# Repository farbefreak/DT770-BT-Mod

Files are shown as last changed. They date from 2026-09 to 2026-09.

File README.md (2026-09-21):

This modification adds Bluetooth, USB-C charging and Audio support to DT-770 Pro Headsets from beyerdynamic.
======

A DIY hardware modification for Beyerdynamic headphones.

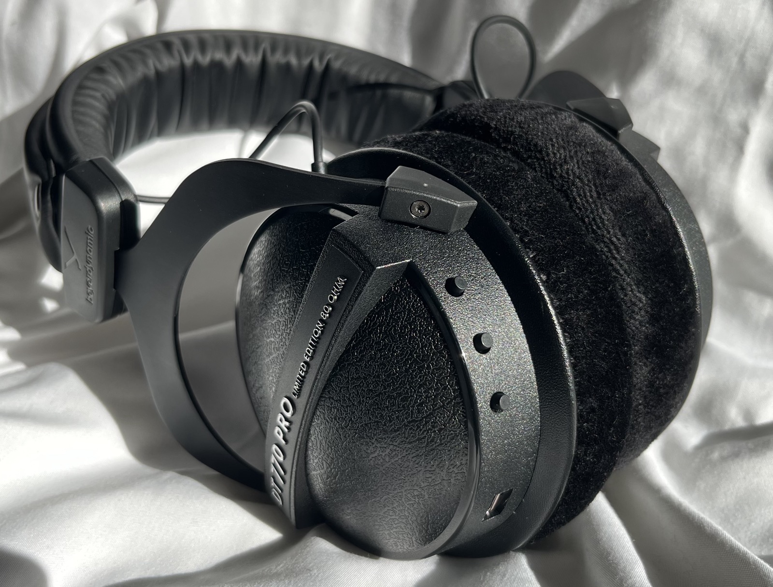
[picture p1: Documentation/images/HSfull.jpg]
Headset full


This project provides everything needed to build the modification yourself, including the PCB design, firmware, 3D-printable parts and a complete assembly guide.
The project is designed to be relatively easy to build. No specialized equipment is required, but basic soldering and mechanical skills are necessary.

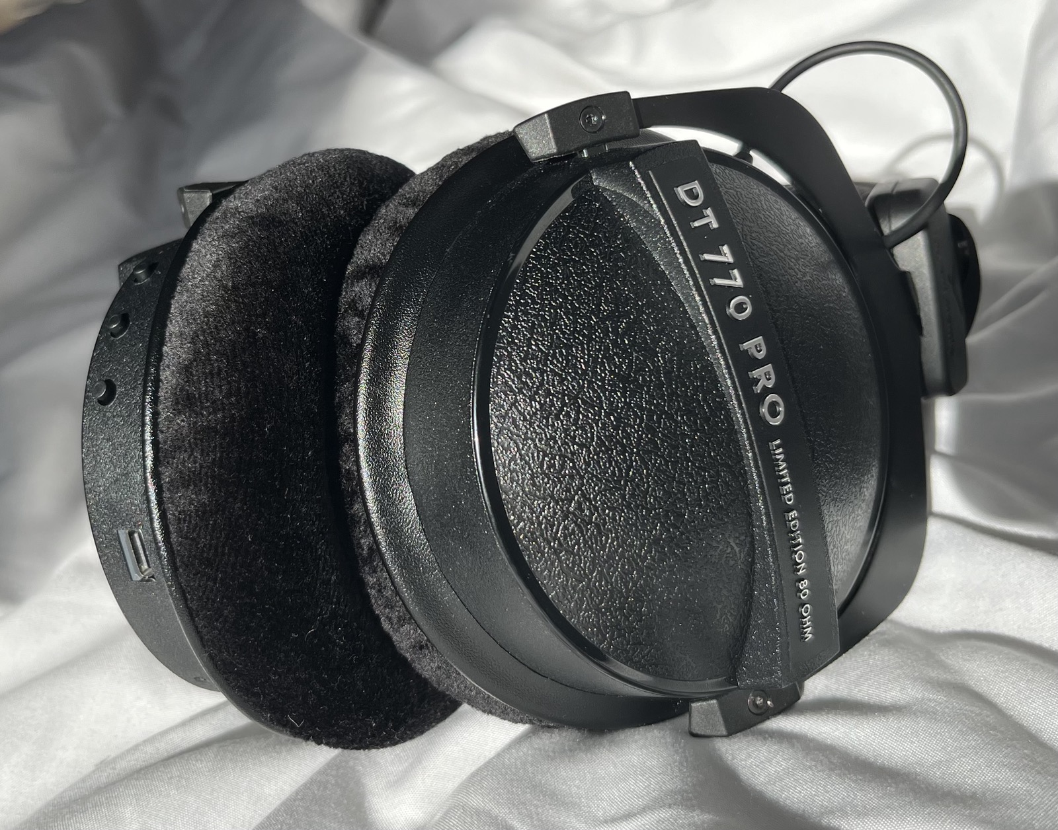
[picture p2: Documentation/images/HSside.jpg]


The modification adds full Bluetooth aptX and A2DP support by using the QCC3008 Chipset. It converts the DT 770 to a fully functional Bluetoooth headset including a microphone back channel and AVRCP controls. (Play/Pause/Vol+/Vol-/Fwrd/Back)
It also adds USB-C battery charging and USB Audio transport. So the Headphones can still be used wired with a USB-C cable.

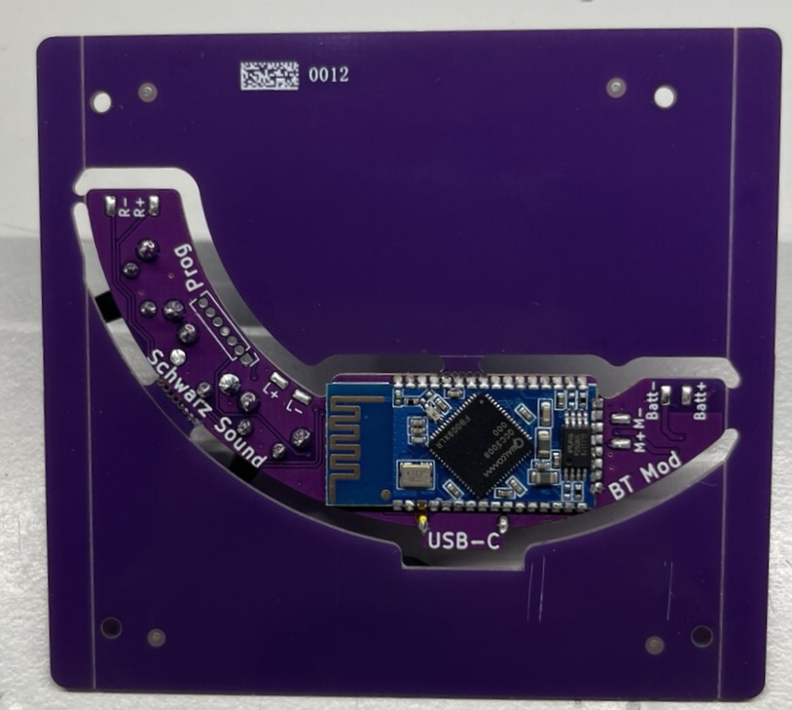
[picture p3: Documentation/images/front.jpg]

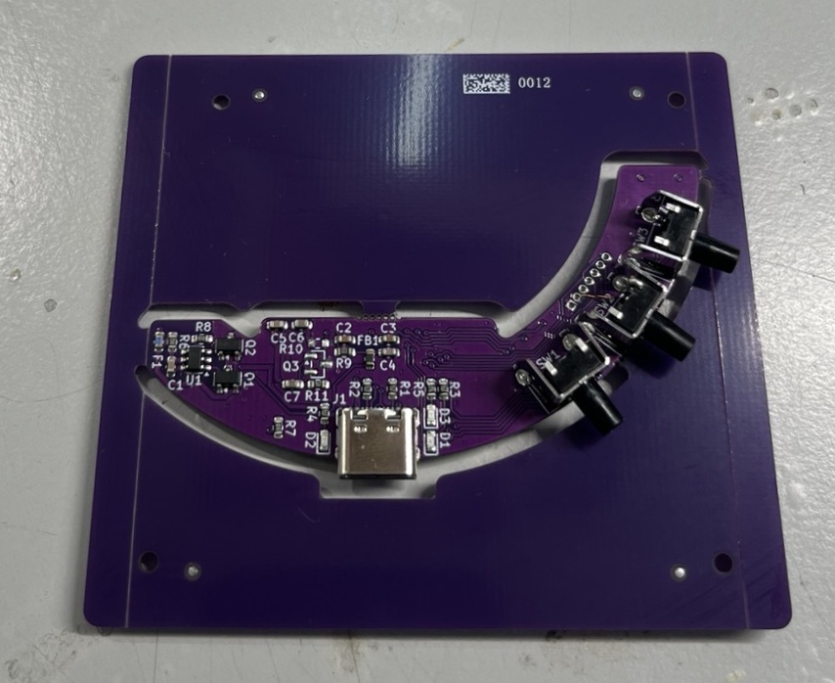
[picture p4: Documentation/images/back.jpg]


The assembly guide can be found in the documentation folder.

### Disclaimer

This project is an independent modification for Beyerdynamic headphones and is not affiliated with, endorsed by, or sponsored by Beyerdynamic
This project involves modification of electronic equipment. The author provides the hardware designs, firmware and documentation "AS IS", without warranty of any kind.
The author assumes no responsibility for damage to headphones, batteries, electronic components, personal property or persons resulting from the use, modification, manufacture or installation of this project.
Use and modification of the project is entirely at the your own risk.

### License

This project is available for personal and non-commercial use.
You are free to study, build and modify the project for your own personal use.
Commercial manufacture, sale or distribution of the project or derivatives is not permitted without explicit permission from the author.

Have fun building!

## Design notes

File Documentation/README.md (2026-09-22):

Assembly
======

# Materials & tools

Tools you need:
* Soldering Iron + Solder + Flux
* Wire Stripper
* T2 Screwdriver
* Flathead Screwdriver
* 4,2mm and 2mm Drill + means of holding it, a battery powered drill works but a Pin Vice would be more controlled
* Hotglue gun
* FDM 3D printer
* SLA 3D printer
* CSR USB SPI Programmer - search for CSR USB-SPI programmer on aliexpress or use this project: https://github.com/lorf/csr-spi-ftdi

Parts:
* Assembled PCB including QCC3008 - QCC3008 on module can be brought on aliexpress, search for BTM306 
* Lithium battery (see below what to choose)
* 6mm Microphone capsule
* DT 770 headphones
* 26AWG / 0,15mm^2 Wire

# Process steps:
+ Print all the parts
+ Program the PCB
+ disassemble the Headphones
+ attach the Lightpipe
+ solder the microphone and glue it into the Headphone casing
+ glue the PCB in
+ solder the battery
+ assemble everything

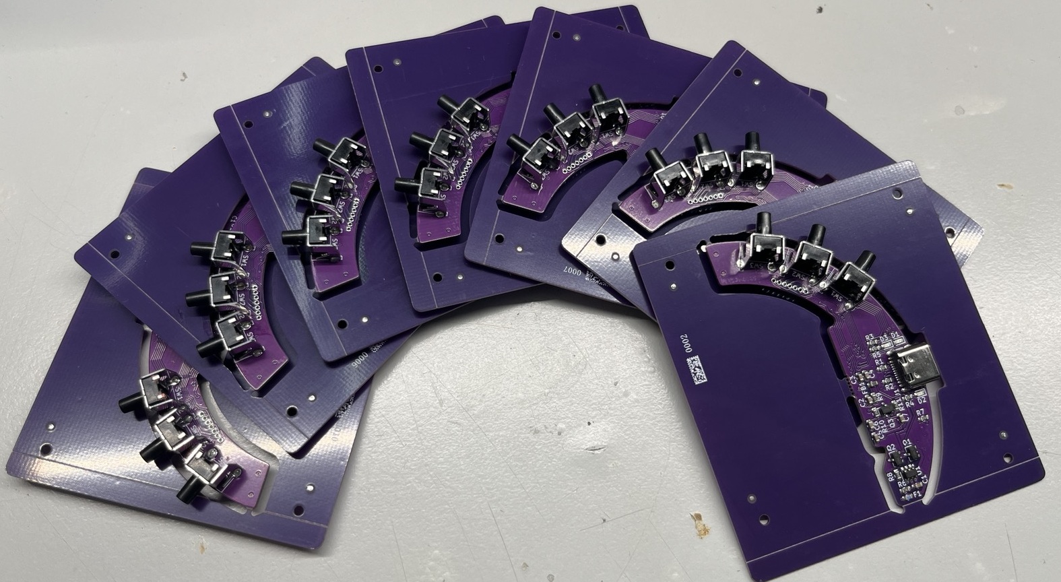
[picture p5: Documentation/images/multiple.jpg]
PCBs


# Programming
Solder a 1,27mm Pin header to some wires. To program the PCB just plug the pin header into the PCB and hold it on an angle to make contact. 
Pin out is self explanatory, check the PCB files and labelling on the programmer.
"+BATT" doesn't need to be connected if you already have a battery connected. Without a battery, this pin can be connected to the 3,3V output of the CSR USB to supply power to be PCB while programming.
Upload the Config file with the "ADK Configuration Tool". 
+ Open the program
+ connect programmer to PCB
+ select the right device
+ click "go configurable"
+ hold play/pause button to enable PCB
+ under File click "Open Config Set Dump"
+ click "Write Device"
+ click "Go Normal"
done

Set the Bluetooth name by opening PSTool.
Select the right device click "ok" and use the filter to search for "Name".  Add your desired name and click "Set" followed by "Reset & Close" -> done.

# Battery

Many different battery will work. You trade off battery runtime with internal volume and added weight. 
I used a 7,6mm x 18mm x 55mm cell with 600mAh. This cell is relatively big and needs modifications to the internal "cage". Three posts need to be cut out.
The maximum size that fits in the internal cage without modification is 8x10x50mm. so a 801050 cell. This cell fits in the internal slot of the cup.
Even a 100mAh cell will give good batter runtime of ~ 5h depending on listening volume.
A protected cell isn't necessary here as the circuit already includes short circuit, over charge and over discharge protection. 
The current PCB doesn't feature a battery NTC to halt charging at extreme temperatures. So make sure to only charge in room temp environments. (or change the PCB and software to include it)

# LED Indicators
There are 3 LEDs to display the current status Red/Green/Blue. The light pipe makes them visible on the USB-C port.
Everything here can be configured according to your liking. The current config file results in the following behaviour:
* Red LED -> shows battery status and charging status. When the battery state is lower than 10%, the red lights starts pulsing. When charging, the red light is solid.
* Blue LED -> shows Bluetooth availability, when no bluetooth device is connected this light is flashing
* Green LED -> shows connection and charging status, when a Bluetooth device is connected this LED fades slowly. When a device is sending audio, this light fades fast. When the battery is fully charged, this light turns solid.

# Button functions
The three buttons can be reconfigured. Current setup reacts like this:
* Upper button -> "single click" Volume increase, "click and hold" Volume increase constantly, "Double click" next title
* Upper button -> "single click" play/pause, "click and hold" power off/on, "Double click" enter bluetooth peering
* Lower button -> "single click" Volume decrease, "click and hold" Volume decrease constantly, "Double click" last title

## Disassembly
###### Attention! The pictures show revision 1 of all the parts. The microphone placement and pcb changed a little. The guide still works the same.

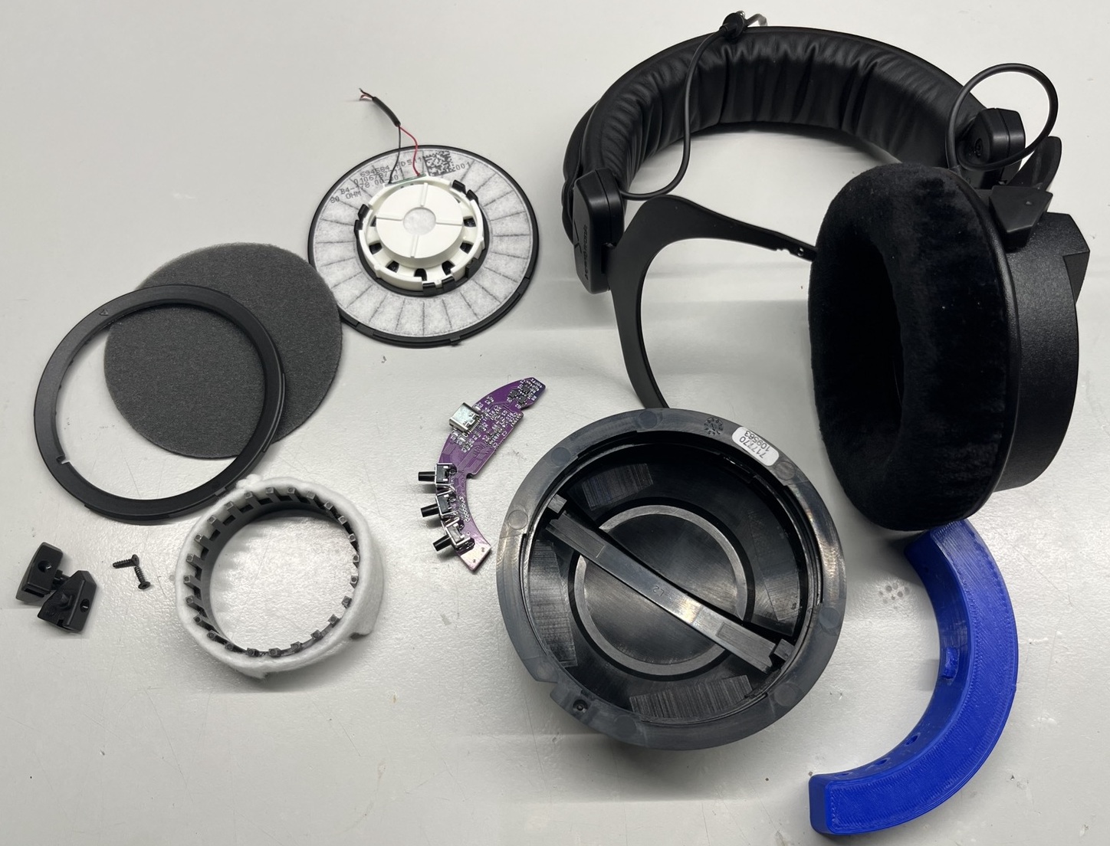
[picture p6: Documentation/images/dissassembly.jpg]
Disassembly


Use the T2 screwdriver to remove the headband holders from the left ear cup. Remove the ear cushions by carefully sliding them from the rim.
A flathead screwdriver can now be inserted in slots around the ring that hold the driver inside. Use a prying motion to unclip the ring. 
Desolder all wires from the driver - including the wire for the right side driver as well as the audio input cable. 
Remove both cables from the cup by pulling the metal clips from the strain relive. 
The left Earcup should now be completely free.
Keep all the parts safe except for the Audio input wire. It can be discarded as its not needed anymore.

## Cup modifications

Attach the printed drill guide by sliding it into the bottom hole (the one where the audio cable used to be).

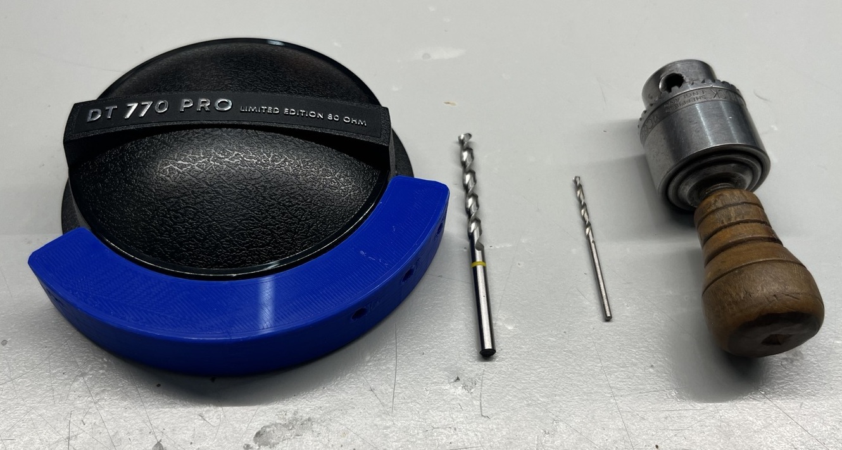
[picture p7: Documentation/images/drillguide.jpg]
drillguide


Drill the 2mm microphone hole first. Its location isnt super critical. Keep the 2mm drill bit in the formed hole to keep the guide aligned while drilling the button holes.

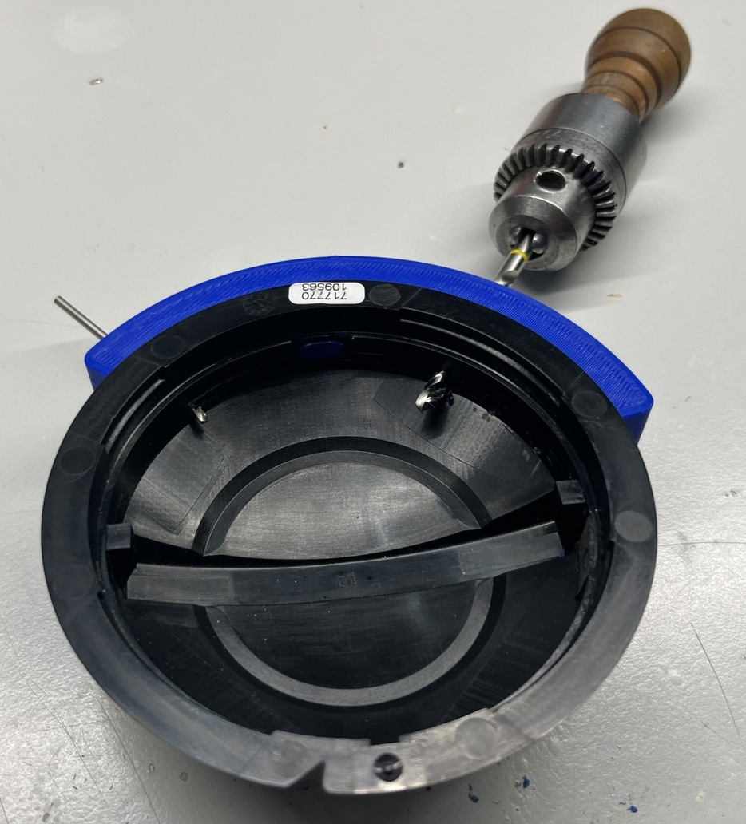
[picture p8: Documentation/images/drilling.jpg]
drilling


Drill the remaining 3 holes. Make sure to keep the guide aligned. Its easy with a pin vice but a battery powered drill works too.

You should end up with 4 clean holes afterwards. 

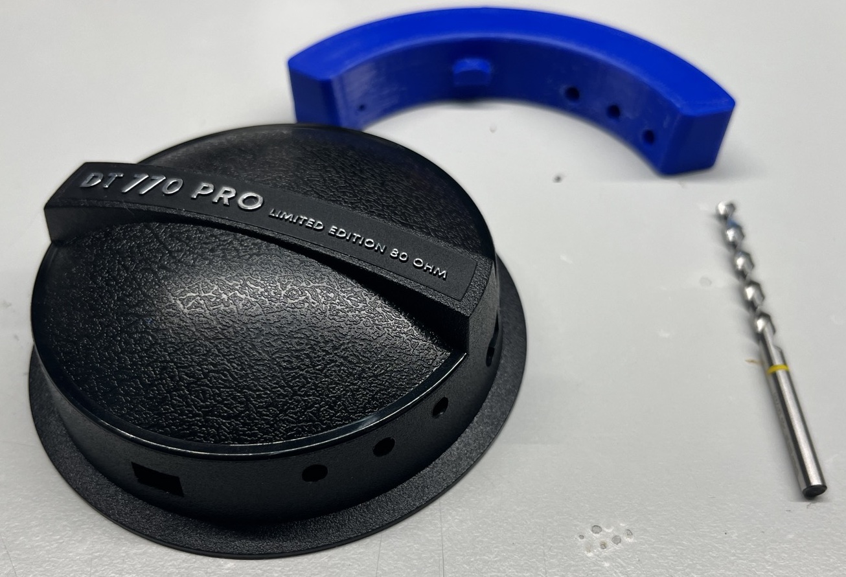
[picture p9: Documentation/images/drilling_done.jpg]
Drilling Done


## Microphone

Glue the printed Mic holder into the ear cup centered over the drilled 2mm hole. Use the angled face on the print to align the holder. Make sure to not fill the 2mm hole or the printed part. Just a little glue on the outside is all thats needed. 

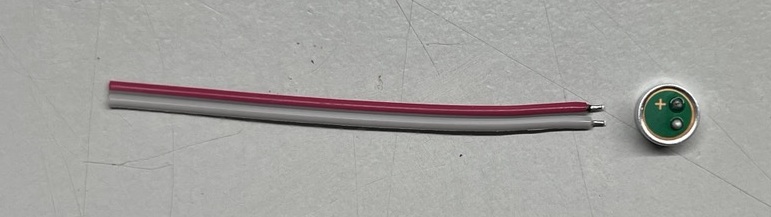
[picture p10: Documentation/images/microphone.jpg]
microphone


Solder 50mm wire to the Mic. I used color coded flat ribbon but everything works. You can even use a bit of the discarded audio input wire. 

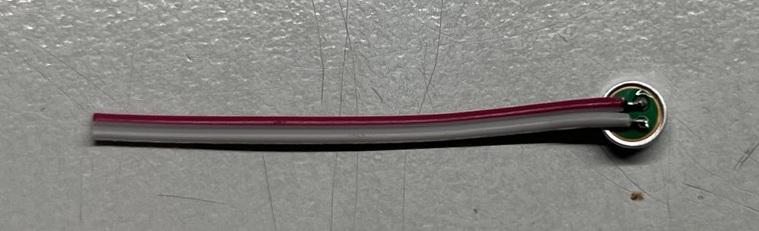
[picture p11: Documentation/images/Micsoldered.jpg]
microphone soldered


Press the mic into the printed holder and seal the backside with hotglue.

## Lightpipe

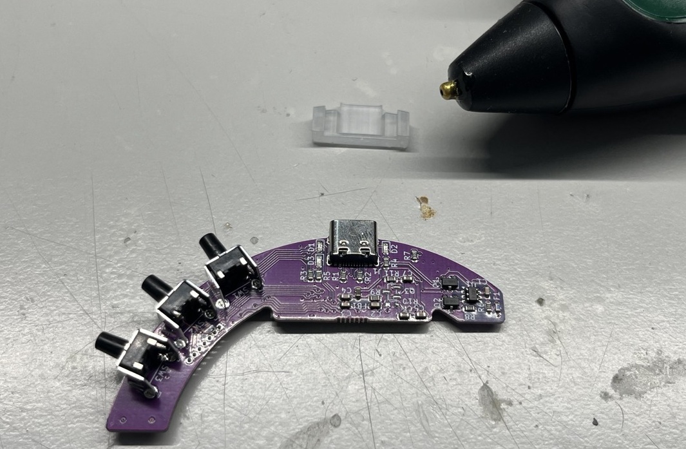
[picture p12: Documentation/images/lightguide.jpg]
lightguide


###### Use translucent Hotglue!
Apply two small drops of hot glue to the LEDs next to the USB-C connector. Press the lightpipe into it and keep it aliged to the PCB edge while the glue is still warm.

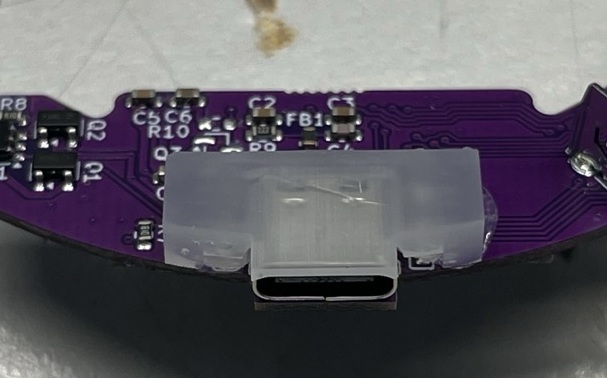
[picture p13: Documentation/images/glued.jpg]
glued


Sqeeze out left and right of the connector doesnt matter and is expected. It wont interfere so dont worry about it.

## Glue the PCB into the earcups

Slide the PCB into the housing. Start with the upper button and work your way towards the USB connector. 

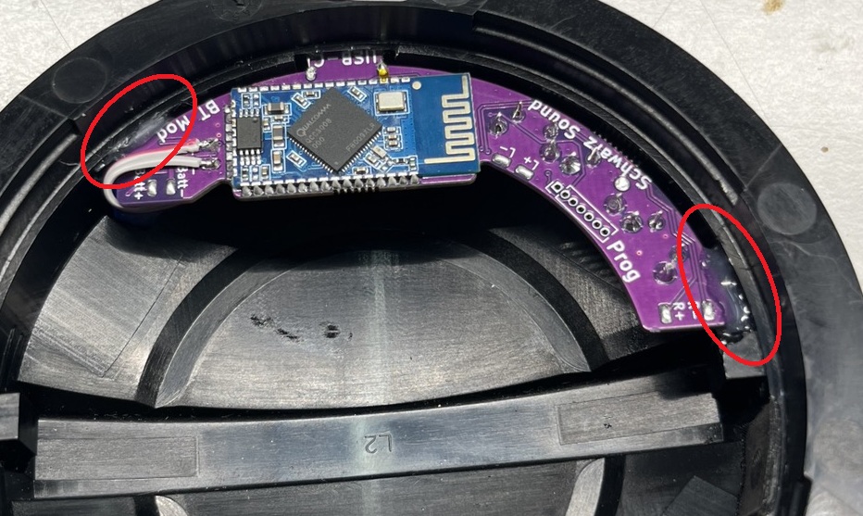
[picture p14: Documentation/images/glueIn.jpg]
PCB glued


Apply two small drops of hot glue to keep it in place. Make sure the board is aligned while the glue hardens. 
Repeatedly click the buttons to make sure they spring back. If the board isn't aligned properly, the button may stay stuck!

## Solder the wires 

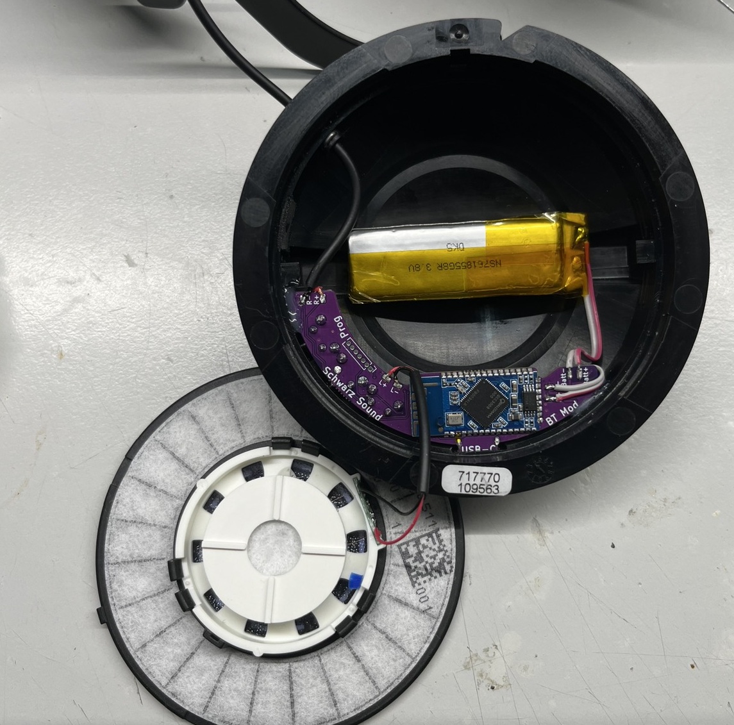
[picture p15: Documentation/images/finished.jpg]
Done


Attach the battery last. The board goes live when you do so solder the drivers and microphone first to avoid shorts.

Now you are almost done. Close the headphones up - same as disassembly but in reverse ;)
Check for interference by checking if the driver sits flush and doesnt apply force to anything. Make sure all wires are where they belong and clip the ring back in. 

I found it easiest to twist the ear cushions onto the rim.

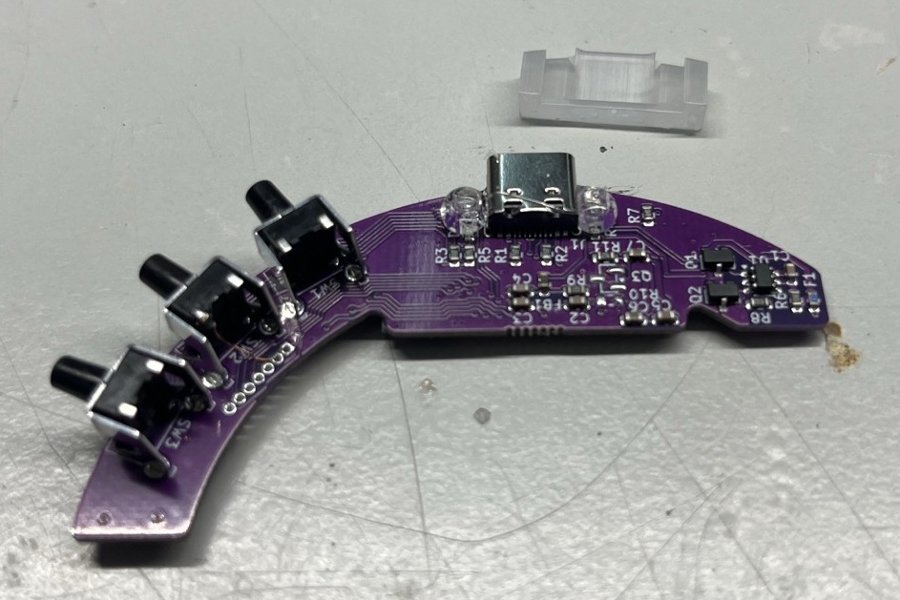
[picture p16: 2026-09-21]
Documentation/images/Lightpipe_glue.jpg

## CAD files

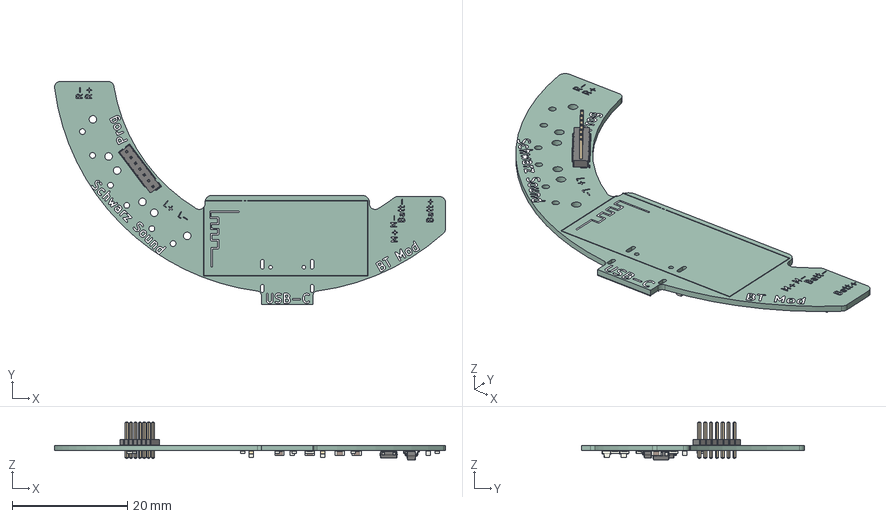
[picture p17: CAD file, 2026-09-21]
Mechanical/PCB.step
67.9 x 38.8 x 6.59 mm
PinHeader_1x07_P127mm_Vertical
C_0603_1608Metric x 6
LED_0603_1608Metric x 3
SOT-23-6
R_0603_1608Metric x 10
L_0603_1608Metric
SOT-23 x 2
Fuse_0603_1608Metric
DT770 Bluetooth Mod_silkscreen x 2
DT770 Bluetooth Mod_PCB

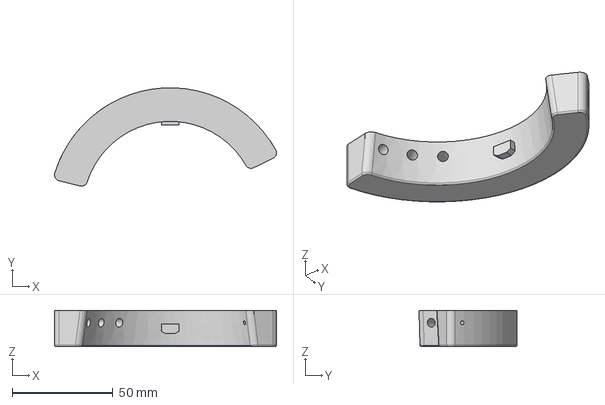
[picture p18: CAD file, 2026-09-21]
Mechanical/drillguide.step
110.3 x 48.9 x 18.0 mm

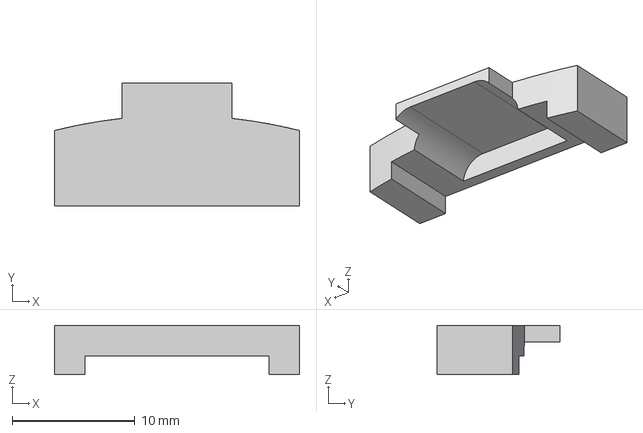
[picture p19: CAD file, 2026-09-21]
Mechanical/Lightguide.step
20.0 x 10.0 x 4.00 mm

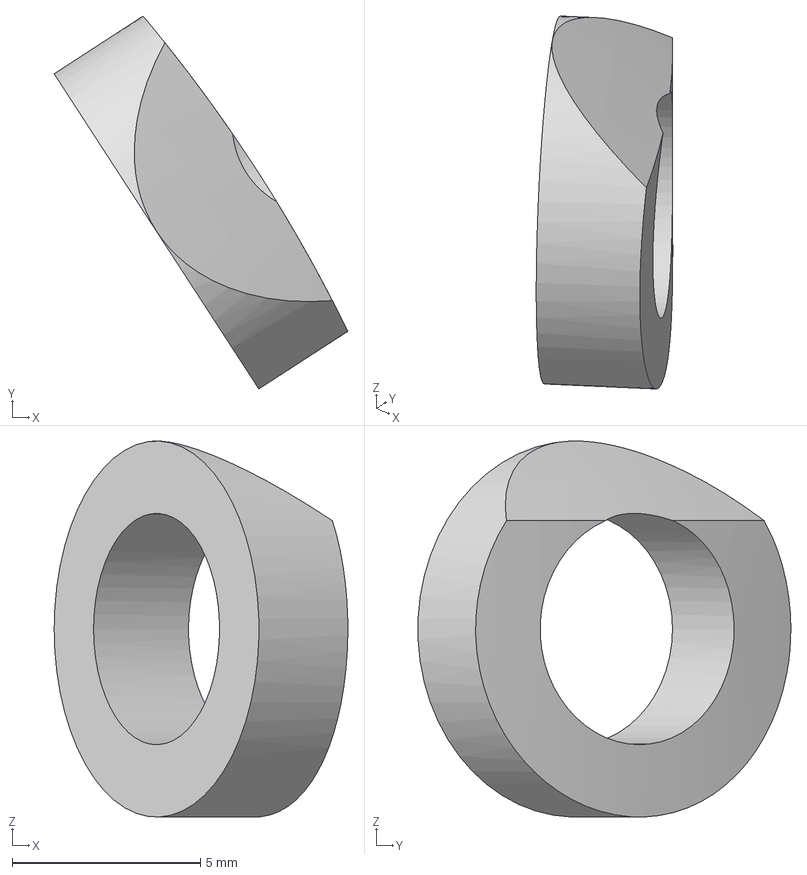
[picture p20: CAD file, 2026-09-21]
Mechanical/microphone_holder.step
7.81 x 9.92 x 10.00 mm

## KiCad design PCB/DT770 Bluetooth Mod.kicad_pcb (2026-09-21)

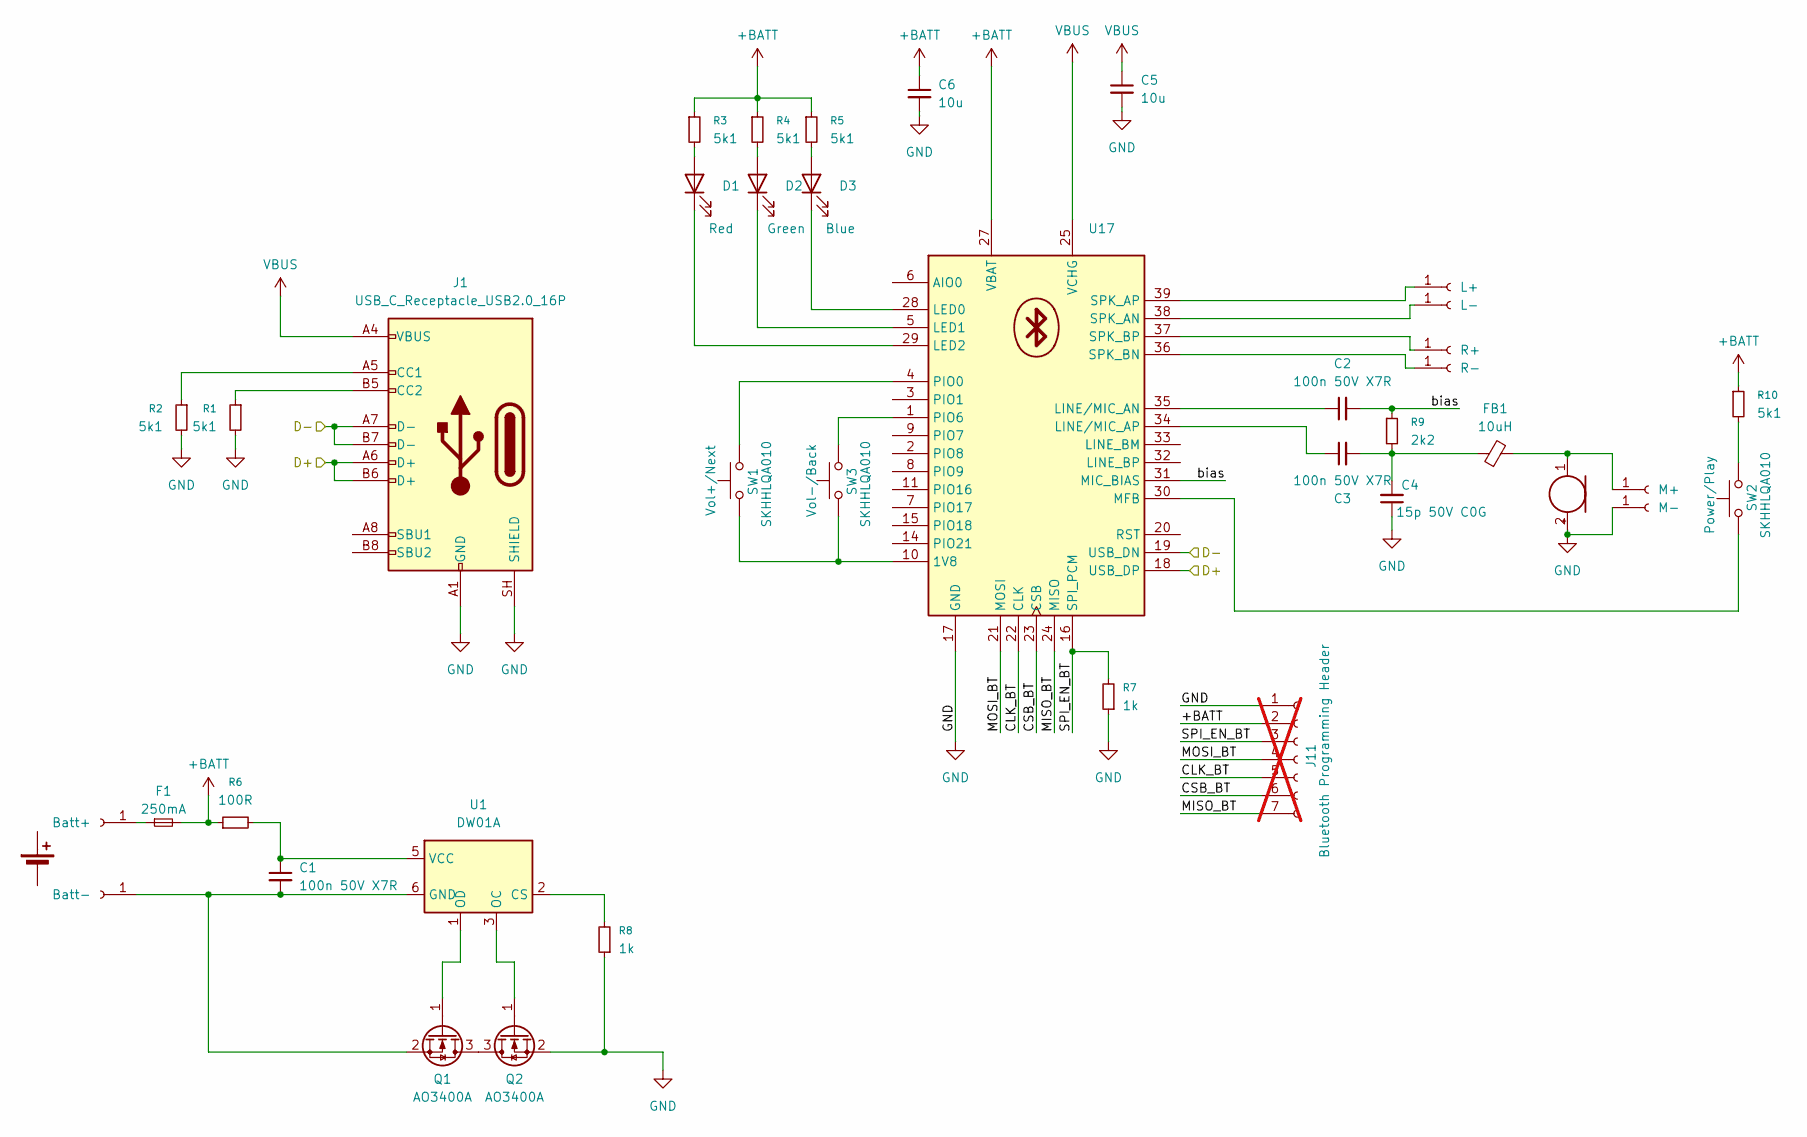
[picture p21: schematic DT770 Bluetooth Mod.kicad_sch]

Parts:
BT1: Battery_Cell
C1, C2, C3: 100n 50V X7R; C_0603_1608Metric; MPN CC0603KRX7R9BB104; LCSC C14663
C4: 15p 50V C0G; C_0603_1608Metric; MPN CL10C150JB8NNNC; LCSC C1644
C5, C6: 10u; C_0603_1608Metric; Voltage 10V; MPN CL10A106KP8NNNC; LCSC C19702
D1: Red; LED_0603_1608Metric; MPN CT-1608URC-P4; LCSC C52675987
D2: Green; LED_0603_1608Metric; MPN CT-1608UGC-P4; LCSC C52675989
D3: Blue; LED_0603_1608Metric; MPN CT-1608UBC-P4; LCSC C52675990
F1: 250mA; Fuse_0603_1608Metric; MPN F06F0.25; LCSC C2924952
FB1: 10uH; L_0603_1608Metric; MPN SDFL1608S100KTF; LCSC C1035
J1: USB_C_Receptacle_USB2.0_16P; USB_C_Receptacle_G-Switch_GT-USB-7010ASV; MPN MLD-TYPE-C-3.1-16PIN-L7.35; LCSC C52766457
J2: L+; SolderWirePad_1x01_SMD_1x2mm
J3: L-; SolderWirePad_1x01_SMD_1x2mm
J4: R+; SolderWirePad_1x01_SMD_1x2mm
J5: R-; SolderWirePad_1x01_SMD_1x2mm
J6: Batt+; SolderWirePad_1x01_SMD_1x2mm
J7: Batt-; SolderWirePad_1x01_SMD_1x2mm
J8: M+; SolderWirePad_1x01_SMD_1x2mm
J9: M-; SolderWirePad_1x01_SMD_1x2mm
J11: Bluetooth Programming Header; PinHeader_1x07_P1.27mm_Vertical; not fitted
MK1: Microphone; SolderWirePad_1x01_SMD_1x2mm; MPN HMB-O40J42-CWH96; LCSC C50198762
Q1, Q2: AO3400A; SOT-23; MPN AO3400A; LCSC C20917
R1, R2, R3, R4, R5, R10: 5k1; R_0603_1608Metric; MPN 0603WAF5101T5E; LCSC C23186
R6: 100R; R_0603_1608Metric; MPN 0603WAF1000T5E; LCSC C22775
R7, R8: 1k; R_0603_1608Metric; MPN 0603WAF1001T5E; LCSC C21190
R9: 2k2; R_0603_1608Metric; MPN 0603WAF2201T5E; LCSC C4190
SW1, SW2, SW3: SKHHLQA010; SW_Tactile_SKHH_Angled; MPN SKHHLQA010; LCSC C125034
U1: DW01A; SOT-23-6; MPN DW01-A/J; LCSC C2909013
U17: Unbenannt

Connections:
+BATT: C6.1, F1.2, J11.2, R3.1, R4.1, R5.1, R6.1, R10.1, U17.27 (VBAT)
/CLK_BT: J11.5, U17.22 (CLK)
/CSB_BT: J11.6, U17.23 (CSB)
/D+: J1.A6 (D+), J1.B6 (D+), U17.18 (USB_DP)
/D-: J1.A7 (D-), J1.B7 (D-), U17.19 (USB_DN)
/MISO_BT: J11.7, U17.24 (MISO)
/MOSI_BT: J11.4, U17.21 (MOSI)
/SPI_EN_BT: J11.3, R7.2, U17.16 (SPI_PCM)
/bias: C2.2, R9.1, U17.31 (MIC_BIAS)
GND: C4.1, C5.2, C6.2, J1.A1 (GND), J1.A12 (GND), J1.B1 (GND), J1.B12 (GND), J1.SH (SHIELD), J9.1 (Pin_1_1), J11.1, MK1.2 (+), Q2.2 (S), R1.2, R2.2, R7.1, R8.1, U17.17 (GND), U17.26 (GND), U17.40 (GND)
unnamed: C3.2, C4.2, FB1.1, R9.2
unnamed: D1.2 (A), R3.2
unnamed: D1.1 (K), U17.29 (LED2)
unnamed: D2.2 (A), R4.2
unnamed: D2.1 (K), U17.5 (LED1)
unnamed: D3.2 (A), R5.2
unnamed: D3.1 (K), U17.28 (LED0)
unnamed: J1.A5 (CC1), R2.1
unnamed: J1.B5 (CC2), R1.1
unnamed: J2.1 (Pin_1_1), U17.39 (SPK_AP)
unnamed: J3.1 (Pin_1_1), U17.38 (SPK_AN)
unnamed: J4.1 (Pin_1_1), U17.37 (SPK_BP)
unnamed: J5.1 (Pin_1_1), U17.36 (SPK_BN)
unnamed: F1.1, J6.1 (Pin_1_1)
unnamed: C1.2, J7.1 (Pin_1_1), Q1.2 (S), U1.6 (GND)
unnamed: FB1.2, J8.1 (Pin_1_1), MK1.1 (-)
unnamed: Q1.3 (D), Q2.3 (D)
unnamed: Q1.1 (G), U1.1 (OD)
unnamed: Q2.1 (G), U1.3 (OC)
unnamed: R10.2, SW2.1
unnamed: R8.2, U1.2 (CS)
unnamed: C1.1, R6.2, U1.5 (VCC)
unnamed: SW1.1, SW3.1, U17.10 (1V8)
unnamed: C2.1, U17.35 (LINE/MIC_AN)
unnamed: C3.1, U17.34 (LINE/MIC_AP)
unnamed: SW2.2, U17.30 (MFB)
unnamed: SW1.2, U17.4 (PIO0)
unnamed: SW3.2, U17.1 (PIO6)
VBUS: C5.1, J1.A4 (VBUS), J1.A9 (VBUS), J1.B4 (VBUS), J1.B9 (VBUS), U17.25 (VCHG)

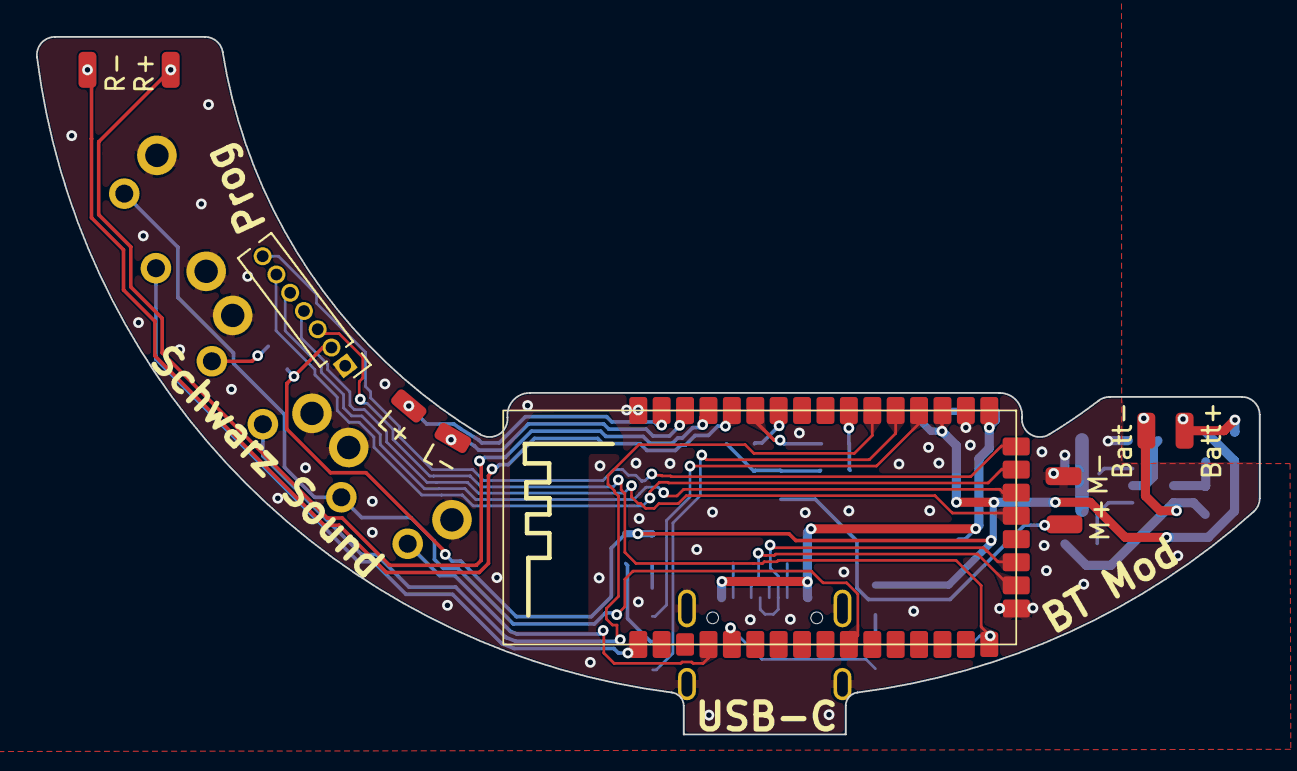
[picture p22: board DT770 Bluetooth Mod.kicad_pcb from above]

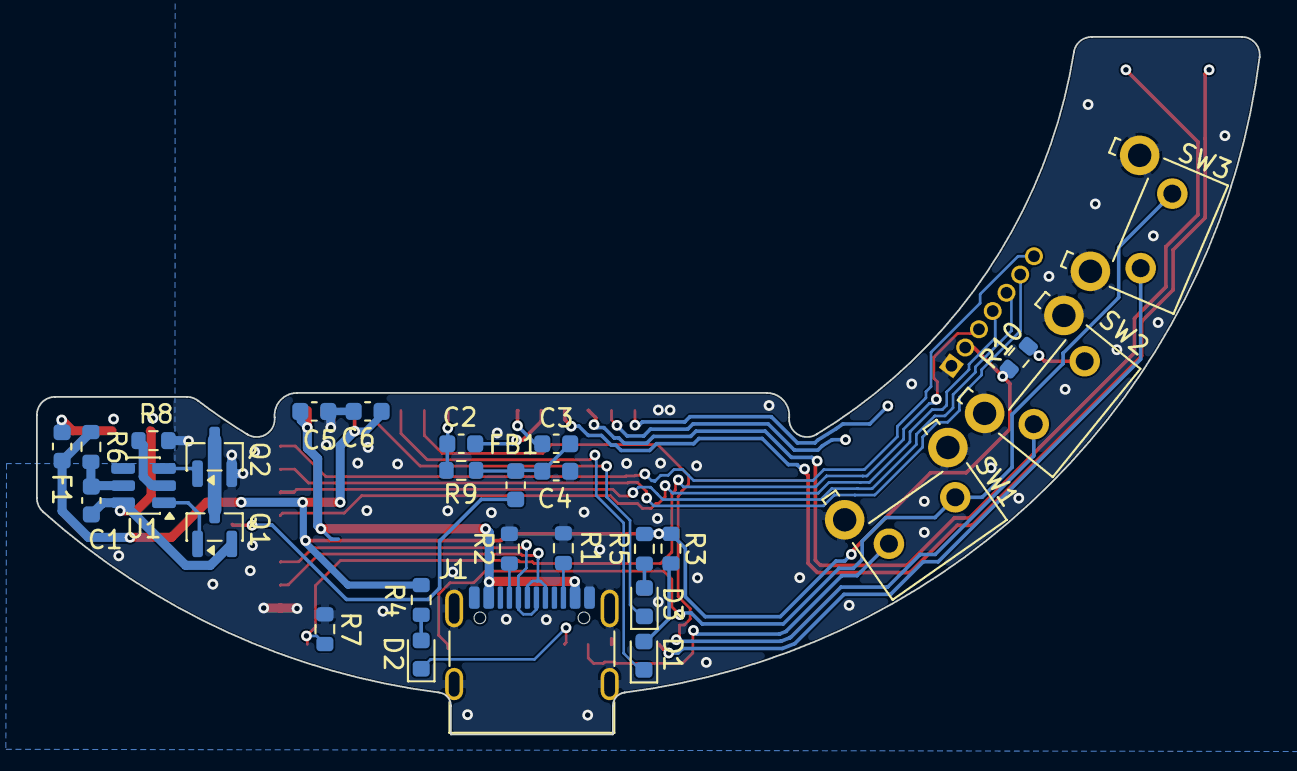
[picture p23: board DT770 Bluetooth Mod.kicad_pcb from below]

Board: 2 copper layers, 67.9 x 38.8 mm, 38 parts (28 on the bottom side), 39 nets.

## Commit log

2026-09-14 First Commit, added KiCad files
    [DT770 Bluetooth Mod.kicad_pcb, DT770 Bluetooth Mod.kicad_sch, DT770 Bluetooth Mod.step]
2026-09-21 Added V2.0 PCB
    Changed on/off switch to VregEnable to make power on actually possible - removed USB-C reset circuitry
    [DT770 Bluetooth Mod.kicad_pcb, DT770 Bluetooth Mod.kicad_sch]
2026-09-21 uploaded M-CAD / Documentation Images
    [Lightguide.step, PCB.step, drillguide.step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]
2026-09-21 Add assembly and programming instructions to README
    Added detailed assembly instructions, materials, tools, programming steps, battery information, disassembly guide, and cup modifications for the project.
2026-09-21 Enhance README with disassembly and modification steps
    Added disassembly and modification instructions for the DT770-BT Mod project, including details on microphone installation and PCB gluing.
2026-09-21 Add PCB images to README
    Added images of the PCB to the README for better visualization.
2026-09-22 Update README with LED and button function details
    Added sections for LED indicators and button functions in the README.
2026-09-22 Update LED and button functions descriptions in README
2026-09-22 Update sourcing details in README.md
    Added sourcing information for CSR USB SPI Programmer and QCC3008 module.
2026-11-04 Enhance README with RGB LED details and firmware notes
    Updated README to include RGB LED status indicators and clarified firmware redistribution restrictions.
2026-11-04 mention assembly guide in the beginning
2026-11-04 Update README with assembly guide information
    Added a note about the assembly guide location.
2026-11-04 PCB Update V2.1
    more antenna clearance, bigger solder joint distance, removed unnecessary pads
